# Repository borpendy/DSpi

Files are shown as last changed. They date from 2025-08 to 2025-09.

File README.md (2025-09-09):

<div align="center">
  Lower DSpi
</div>

## DSpi
The DSpi is a Dual Screen Linux handheld powered by a Rasberry Pi Compute Module 5, designed primarily for DS emulation. The device features a 5000mah amp battery, Xbox pattern controller with dual analog sticks, Dual 480p DSI touchscreens, Stereo speakers and a DAC + Headphone amp. I reccomend using the Rasbian system image provided in the above files, featuring retropie for single screen systems, and melon DS for true dual screen DS emulation (System image coming soon).

## System Specifications

- Uses any Pi CM5 module (however the CM5 lite 8GB wifi is highly recommended) with 4 A76 cores at 2.4GHz.
- 2*800x480 Waveshare IPS displays, both touchscreen.
- Stereo speakers, using 2*MAX98357 IC amplifiers, over the I2S interface.
- Headphone output, using the PCM5102 DAC + PAM8908 Headphone AMP.
- 5000 Mah LiPo battery, with 5V 3A charging using the BQ25890 1S BMS IC.
- Full size controller using RP2040, and the GP2040CE firmware, including dual analog 3ds slide pads.
- Full 3d printable chassis (In FDM!!! - Tested using neptune 4 pro, using 30% speed for hinges), using GBA SP hinges.

## Other notes
This is still a mostly experimental project, and could still use a lot of work, especially on the software side in improving the user experience. Personally if i was looking to emulate DS, I would get either a 3ds, or one of the new android emulation handhelds, however this has still been a fun project to work on. Future plans for this include swapping the main screen to the new 5" touch display 2, and making some pcb adjustments to reduce the device width.

Shield: [][cc-by-nc-sa]

This work is licensed under a
[Creative Commons Attribution-NonCommercial-ShareAlike 4.0 International License][cc-by-nc-sa].

[][cc-by-nc-sa]

[cc-by-nc-sa]: http://creativecommons.org/licenses/by-nc-sa/4.0/
[cc-by-nc-sa-image]: https://licensebuttons.net/l/by-nc-sa/4.0/88x31.png
[cc-by-nc-sa-shield]: https://img.shields.io/badge/License-CC%20BY--NC--SA%204.0-lightgrey.svg

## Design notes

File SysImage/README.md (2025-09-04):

Lite rasbian image available here: https://mega.nz/file/Jq5HgAIb#aFA1X0YDmTlBf3LAp2G1llmQ2dEHOSqhIo8WoQuP7z0
Lite image is stock rasbian + some scripts for battery functionality

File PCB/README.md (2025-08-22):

<div align="center">
  <h1>DSpi Mainboard PCB</h1>
</div>

<div align="center">
  Image of DSpi Motherboard
</div>

The DSpi PCB has a custom mainboard pcb that provides power, audio and controls to the CM5 module. This must be ordered from a PCB fabricator, and I used and recommend JLCPCB for this.
To ensure all trace impedances are correct, for the usb and display lines, you **must** order the board with the **JLC04161H-7628** layer stackup, AND **1.6 mm** thickness. Get assembly on the top side only, as most components used are SMD, and hard to hand solder. Note that the parts in jlcpcb on the bottom side are different in the final project (4.3mm rather than 6mm), so don't get bottom assembly. My recommended settings for jlcpcb are shown below:

<div align="center">
  Image of JLCPCB Settings
</div>
<p align="center">Recommended JLCPCB Settings (All other values default)</p>

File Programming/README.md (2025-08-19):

# Programming the DSpi motherboard
Some parts of the DSpi mainboard require programming after assembly. The onboard MCU (STM32) is used to control the BMS Chip settings, and must be flashed with the provided code for the mainboard to function. To do this, you need an ST-LINK, and a computer with STM32CUBEIDE - This may not be required, testing whether I2C can be set by CM5.
# Programming the DSpi controller
The DSpi controller uses the GP2040-CE architecture. To install the controller firmware, follow the setup instructions on the gp2040-ce website, seen here: https://gp2040-ce.info/installation. Use the boot button labeled on the mainboard. Once the GP2040 firmware is installed, open the web config, and change the input mode to directinput, and go to addons and enable both analog sticks, with inverted Y for both sticks. The instructions for this are here: https://gp2040-ce.info/web-configurator.
# Flashing the DSpi OS image
Use BalenaEtcher or a similar program to write the included image to an SD card, then insert into the DSpi SD slot before boot. If the correct OS is not installed and inserted, both screens will remain black after boot.

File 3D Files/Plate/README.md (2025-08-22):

Contains top cover, top plate, bottom plate, bottom cover + mount for bottom screen

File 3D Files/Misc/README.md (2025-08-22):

Contains battery mount, fan guide, fan mount, speaker grilles

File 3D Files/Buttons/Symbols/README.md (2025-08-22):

Buttons with symbols, probably need a resin printer to print

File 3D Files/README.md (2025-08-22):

## Design Files
All STLs required to build a DSpi + Blender document with all parts assembled, for reference
<div align="center">
  Image of DSpi Motherboard
  <p align="center">Full DSpi model</p>

</div>

<div align="center">
  Lower DSpi
  <p align="center">Lower half DSpi model</p>
</div>

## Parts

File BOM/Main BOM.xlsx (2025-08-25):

Major Parts: | Link: | Cost (AUD): | Note: BOM does not include assembled components
Waveshare 4.3 inch DSI Screen, touch | https://www.waveshare.com/wiki/43H-800480-IPS | $46.99
Waveshare 5 inch DSI Screen, touch | https://www.waveshare.com/50h-800480-ips.htm | $51.25
3ds slide pad * 2 | https://www.aliexpress.com/item/1005006359586643.html | $28.00
GBA SP Hinges | https://www.aliexpress.com/item/1005006352620165.html | $2.78
Micro Sd Card | Any
Pi Fan | https://www.aliexpress.com/item/1005006617984702.html | $10.00
LiPo Battery | https://www.aliexpress.com/item/1005004816868993.html
FFC Cable - 300mm | https://www.digikey.com.au/en/products/detail/raspberry-pi/SC1132/21658271 | $3.18
Speakers * 2 | https://www.digikey.com.au/en/products/detail/soberton-inc/SP-1605/3973691 | $4.94
CM5 8GB Lite | https://www.digikey.com.au/en/products/detail/raspberry-pi/SC1598/25805587 | $136.33
Speaker cables | https://www.aliexpress.com/item/1005006856354000.html | $5.00
PCB Parts:
top buttons (4.3mm) | https://www.aliexpress.com/item/4001360233985.html | $2.26
side buttons (4.5mm) | https://www.aliexpress.com/item/1005005826296317.html | $1.83
Screws as well

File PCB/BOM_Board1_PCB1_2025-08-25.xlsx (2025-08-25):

No. | Quantity | Comment | Designator | Footprint | Value | Manufacturer Part | Manufacturer | Supplier Part | Supplier
1 | 3 | TS-1088-AR02016 | BOOT,RESET,RST | SW-SMD_L3.9-W3.0-P4.45 |  | TS-1088-AR02016 | XUNPU(讯普) | C720477 | LCSC
2 | 2 | 33pF | C2,C62 | C0402 |  | 0402CG330J500NT | FH(风华) | C1562 | LCSC
3 | 14 | 10uF | C3,C5,C6,C9,C18,C19,C20,C26,C36,C40,C42,C52,C53,C66 | C0805 | 10uF | CL21A106KAYNNNE | SAMSUNG(三星) | C15850 | LCSC
4 | 13 | 100nF | C7,C13,C14,C15,C16,C55,C58,C59,C60,C61,C63,C64,C65 | C0402 |  | CL05B104KO5NNNC | SAMSUNG(三星) | C1525 | LCSC
5 | 3 | 22uF | C10,C11,C12 | C0805 | 22uF | CL21A226MAQNNNE | SAMSUNG(三星) | C45783 | LCSC
6 | 11 | 1uF | C17,C25,C33,C37,C82,C83,C84,C85,C87,C88,C89 | C0603 | 1uF | CL10A105KB8NNNC | SAMSUNG(三星) | C15849 | LCSC
7 | 10 | 100nF | C27,C28,C29,C30,C41,C43,C54,C67,C68,C69 | C0402 | 100nF | CL05B104KB54PNC | SAMSUNG(三星) | C307331 | LCSC
8 | 1 | 47nF | C34 | C0603 | 47nF | CL10B473KB8NNNC | SAMSUNG(三星) | C1622 | LCSC
9 | 1 | 4.7uF | C35 | C0603 | 4.7uF | CL10A475KO8NNNC | SAMSUNG(三星) | C19666 | LCSC
10 | 2 | 47uF | C38,C39 | C1206 | 47uF | CL31A476MPHNNNE | SAMSUNG(三星) | C96123 | LCSC
11 | 2 | 1uF | C56,C57 | C0402 |  | CL05A105KA5NQNC | SAMSUNG(三星) | C52923 | LCSC
12 | 3 | 2.2uF | C70,C71,C86 | C0603 | 2.2uF | CL10A225KO8NNNC | SAMSUNG(三星) | C23630 | LCSC
13 | 4 | 10uF | C72,C73,C74,C75 | C0805 | 10uF | GRM21BR61H106KE43L | muRata(村田) | C440198 | LCSC
14 | 4 | 100nF | C76,C77,C78,C79 | C0603 | 100nF | CC0603KRX7R9BB104 | YAGEO(国巨) | C14663 | LCSC
15 | 2 | 2.2nF | C80,C81 | C0805 | 2.2nF | CL21C222JBFNNNE | SAMSUNG(三星) | C28260 | LCSC
16 | 2 | 20pF | C92,C93 | C0402 | 20pF | 0402CG200J500NT | FH(风华) | C1554 | LCSC
17 | 1 | 100nF | C94 | C0402 | 100nF | CL05B104KO5NNNC | SAMSUNG(三星) | C1525 | LCSC
18 | 1 | 5033981892 | CARD1 | TF-SMD_503398-1892 |  | 5033981892 | MOLEX | C428492 | LCSC
19 | 2 | DF40HC(3.0)-100DS-0.4V(51) | CN1,CN2 | CONN-SMD_DF40HC-3.0-100DS-0.4V-51 |  | DF40HC(3.0)-100DS-0.4V(51) | HRS(广濑) | C424649 | LCSC
20 | 1 | B2B-PH-K-S(LF)(SN) | CN5 | CONN-TH_B2B-PH-K-S |  | B2B-PH-K-S(LF)(SN) | JST | C131337 | LCSC
21 | 1 | BM04B-SRSS-TB(LF)(SN) | CN10 | CONN-SMD_BM04B-SRSS-TB |  | BM04B-SRSS-TB(LF)(SN) | JST | C160390 | LCSC
22 | 1 | PJ-320D | CN12 | AUDIO-SMD_PJ-320D |  | PJ-320D | SHOU HAN(首韩) | C431535 | LCSC
23 | 2 | AFC01-S22FCA-00 | FPC1,FPC2 | FPC-SMD_P0.5-22P_FGS-XJ-H2.0 |  | AFC01-S22FCA-00 | JS(钜硕电子) | C262668 | LCSC
24 | 1 | PZ254V-11-05P | H3 | hdr-th_5p-p2.54-v-m |  | PZ254V-11-05P | XFCN(兴飞) | C492404 | LCSC
25 | 2 | 1uH | L2,L3 | IND-SMD_L4.4-W4.2 | 1uH | FXL0420-1R0-M | cjiang(长江微电) | C167203 | LCSC
26 | 2 | KT-0603W | LED1,LED2 | LED0603-R-RD_WHITE |  | KT-0603W | KENTO | C2290 | LCSC
27 | 2 | KT-0603R | LED3,LED4 | LED0603-RD |  | KT-0603R | KENTO | C2286 | LCSC
28 | 4 | 2.2kΩ | R1,R3,R4,R5 | R0402 | 2.2kΩ | 0402WGF2201TCE | UNI-ROYAL(厚声) | C25879 | LCSC
29 | 1 | 15kΩ | R2 | R0402 | 15kΩ | 0402WGF1502TCE | UNI-ROYAL(厚声) | C25756 | LCSC
30 | 3 | 1kΩ | R6,R39,R55 | R0402 | 1kΩ | 0402WGF1001TCE | UNI-ROYAL(厚声) | C11702 | LCSC
31 | 2 | 5.1kΩ | R11,R12 | R0402 | 5.1kΩ | 0402WGF5101TCE | UNI-ROYAL(厚声) | C25905 | LCSC
32 | 1 | 120Ω | R16 | R0603 | 120Ω | 0603WAF1200T5E | UNI-ROYAL(厚声) | C22787 | LCSC
33 | 3 | 10kΩ | R17,R18,R31 | R0603 | 10kΩ | 0603WAF1002T5E | UNI-ROYAL(厚声) | C25804 | LCSC
34 | 1 | 4.7kΩ | R27 | R0402 | 4.7kΩ | 0402WGF4701TCE | UNI-ROYAL(厚声) | C25900 | LCSC
35 | 1 | 750kΩ | R29 | R0603 | 750kΩ | 0603WAF7503T5E | UNI-ROYAL(厚声) | C23240 | LCSC
36 | 1 | 100kΩ | R30 | R0603 | 100kΩ | 0603WAF1003T5E | UNI-ROYAL(厚声) | C25803 | LCSC
37 | 1 | 1.5kΩ | R32 | R0402 | 1.5kΩ | 0402WGF1501TCE | UNI-ROYAL(厚声) | C25867 | LCSC
38 | 1 | 220kΩ | R34 | R0402 | 220kΩ | 0402WGF2203TCE | UNI-ROYAL(厚声) | C25767 | LCSC
39 | 2 | 10kΩ | R37,R38 | R0402 | 10kΩ | 0402WGF1002TCE | UNI-ROYAL(厚声) | C25744 | LCSC
40 | 4 | 56kΩ | R43,R44,R45,R46 | R0402 | 56kΩ | 0402WGF5602TCE | UNI-ROYAL(厚声) | C25796 | LCSC
41 | 2 | 22Ω | R47,R48 | R0402 |  | 0402WGF220JTCE | UNI-ROYAL(厚声) | C25092 | LCSC
42 | 4 | 1kΩ | R49,R50,R51,R54 | R0402 |  | 0402WGF1001TCE | UNI-ROYAL(厚声) | C11702 | LCSC
43 | 2 | 10kΩ | R52,R53 | R0402 |  | 0402WGF1002TCE | UNI-ROYAL(厚声) | C25744 | LCSC
44 | 2 | 470Ω | R56,R57 | R0805 | 470Ω | 0805W8F4700T5E | UNI-ROYAL(厚声) | C17710 | LCSC
45 | 2 | BM02B-SURS-TF(LF)(SN) | SPKR_L,SPKR_R | CONN-SMD_2P-P0.80_BM02B-SURS-TF-LF-SN |  | BM02B-SURS-TF(LF)(SN) | JST | C385130 | LCSC
46 | 2 | FH19C-4S-0.5SH(10) | STICK-L,STICK-R | FPC-SMD_FH19C-4S-0.5SH |  | FH19C-4S-0.5SH(10) | HRS(广濑) | C424650 | LCSC
47 | 1 | AP22653W6-7 | U1 | SOT-23-6_L2.9-W1.6-P0.95-LS2.8-BR |  | AP22653W6-7 | DIODES(美台) | C2158037 | LCSC
48 | 1 | HDMI-519S | U2 | HDMI-SMD_19P-P0.40-H-F_HDMI-519S |  | HDMI-519S | SOFNG(硕方) | C183605 | LCSC
49 | 3 | RT9742GGJ5 | U4,U15,U19 | TSOT-23-5_L2.9-W1.6-P0.95-LS2.8-BR |  | RT9742GGJ5 | RICHTEK(立锜) | C250547 | LCSC
50 | 1 | STM32F103C8T6 | U5 | LQFP-48_L7.0-W7.0-P0.50-LS9.0-BL |  | STM32F103C8T6 | ST(意法半导体) | C8734 | LCSC
51 | 1 | BQ25890RTWR | U8 | WQFN-24_L4.0-W4.0-P0.50-BL-EP |  | BQ25890RTWR | TI(德州仪器) | C130451 | LCSC
52 | 1 | TPS61022RWUR | U9 | VQFN-7_L2.0-W2.0-P0.55-TL_RWU |  | TPS61022RWUR | TI(德州仪器) | C915088 | LCSC
53 | 2 | MAX98357AETE+T | U11,U12 | TQFN-16_L3.0-W3.0-P0.50-BL-EP1.5 |  | MAX98357AETE+T | ADI(亚德诺)/MAXIM(美信) | C910544 | LCSC
54 | 1 | RP2040 | U16 | LQFN-56_L7.0-W7.0-P0.4-EP |  | RP2040 | Raspberry Pi(树莓派) | C2040 | LCSC
55 | 1 | W25Q128JVSIQTR | U17 | SOIC-8_L5.3-W5.3-P1.27-LS8.0-BL |  | W25Q128JVSIQ | WINBOND(华邦) | C97521 | LCSC
56 | 1 | TPSPX3819M5-L-3-3 | U18 | SOT-23-5_L3.0-W1.6-P0.95-LS2.8-BR |  | TPSPX3819M5-L-3-3 | TECH PUBLIC(台舟) | C5370980 | LCSC
57 | 1 | PCM5102APWR | U20 | TSSOP-20_L6.5-W4.4-P0.65-LS6.4-BL |  | PCM5102APWR | TI(德州仪器) | C107671 | LCSC
58 | 1 | PAM8908JER | U21 | QFN-16_L3.0-W3.0-P0.50-BL-EP1.7 |  | PAM8908JER | DIODES(美台) | C33233 | LCSC
59 | 1 | TYPE-C-31-M-17 | USB2 | USB-C-SMD_10P-P1.00-L6.8-W8.9 |  | TYPE-C-31-M-17 | 韩国韩荣 | C283540 | LCSC
60 | 2 | TYPE-C-31-M-12 | USBC1,USBC2 | USB-C_SMD-TYPE-C-31-M-12 |  | TYPE-C-31-M-12 | 韩国韩荣 | C165948 | LCSC
61 | 1 | 12MHz | X1 | OSC-SMD_4P-L3.2-W2.5-BL |  | X322512MSB4SI | YXC | C9002 | LCSC
62 | 1 | 8MHz | X2 | CRYSTAL-SMD_L5.0-W3.2 | 8MHz | X50328MSB2GI | YXC(扬兴晶振) | C115962 | LCSC

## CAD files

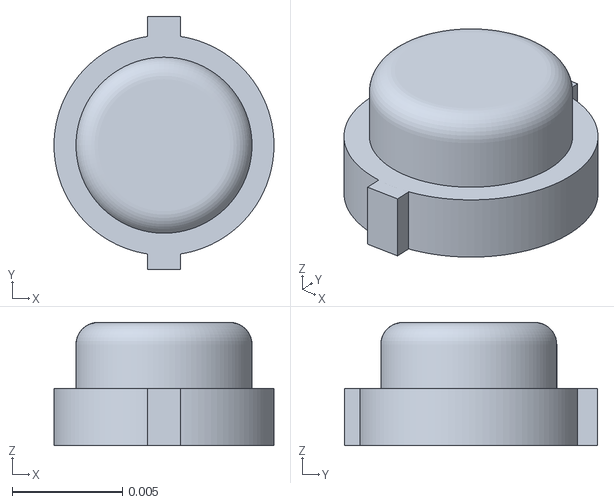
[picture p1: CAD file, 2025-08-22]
3D Files/Buttons/Nosymbols/topbutton.stl
0.01 x 0.0115 x 0.0056

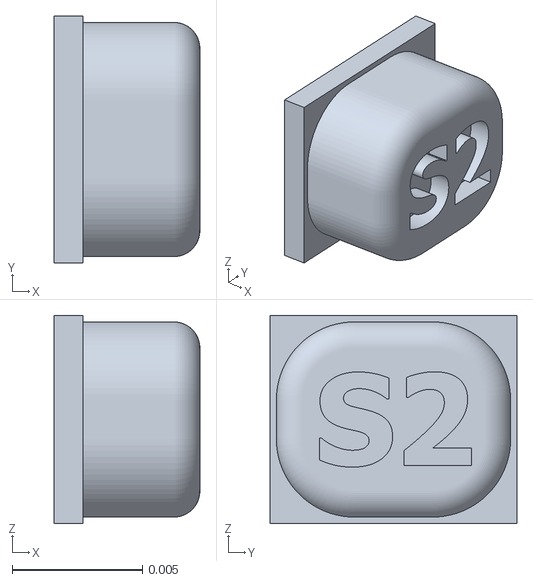
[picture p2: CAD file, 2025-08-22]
3D Files/Buttons/Symbols/s2.stl
0.0056 x 0.00949 x 0.008

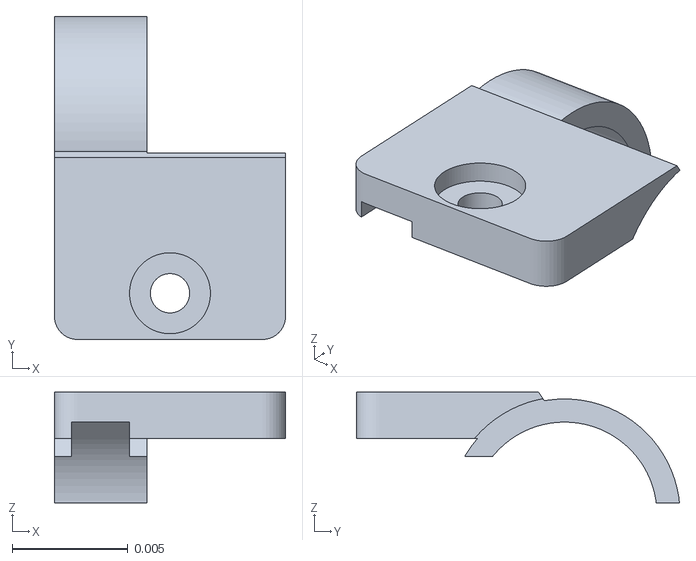
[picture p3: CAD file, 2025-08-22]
3D Files/Hinge/topcover-r.stl
0.01 x 0.014 x 0.0048

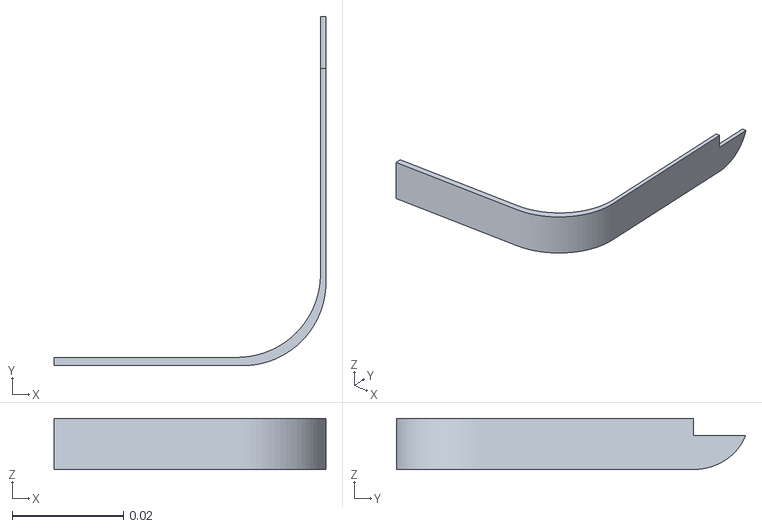
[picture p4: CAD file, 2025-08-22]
3D Files/Misc/fanguide2.stl
0.049 x 0.0629 x 0.0092

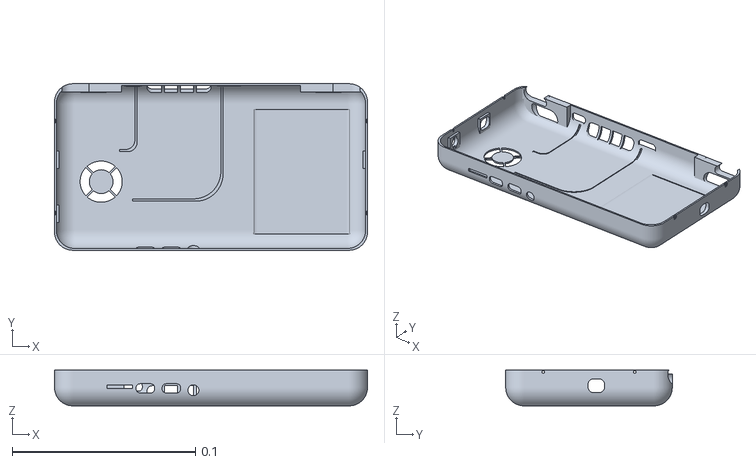
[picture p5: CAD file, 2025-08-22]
3D Files/Plate/bottomcover.stl
0.171 x 0.091 x 0.0195

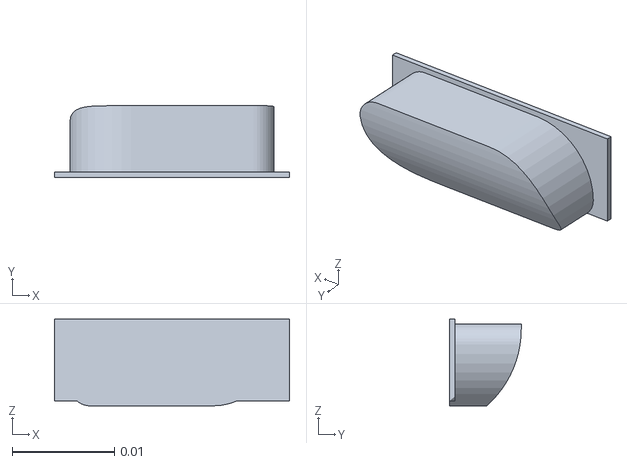
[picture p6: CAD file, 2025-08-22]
3D Files/Buttons/Nosymbols/trigger.stl
0.023 x 0.007 x 0.0085

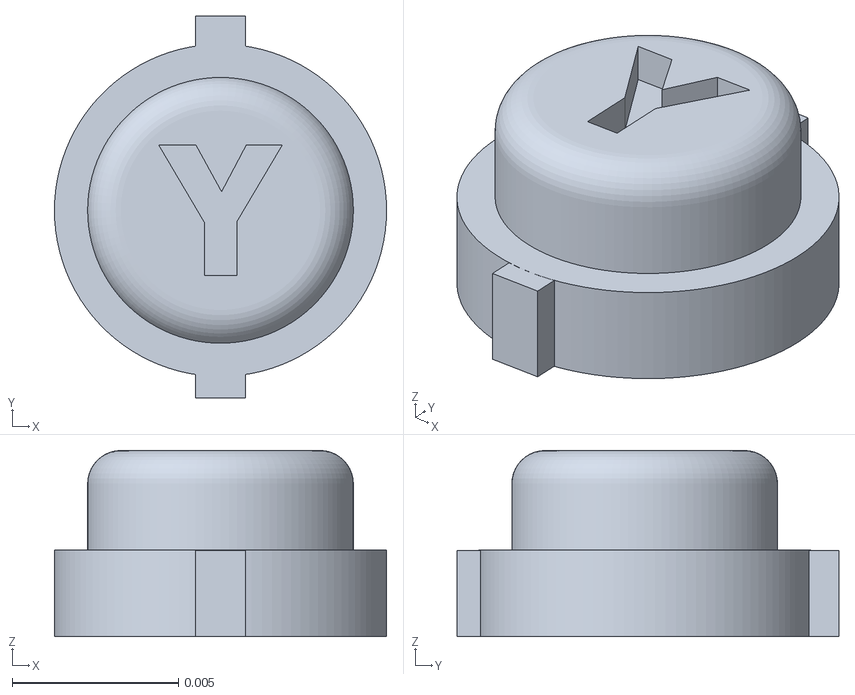
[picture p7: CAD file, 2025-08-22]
3D Files/Buttons/Symbols/y.stl
0.01 x 0.0115 x 0.0056

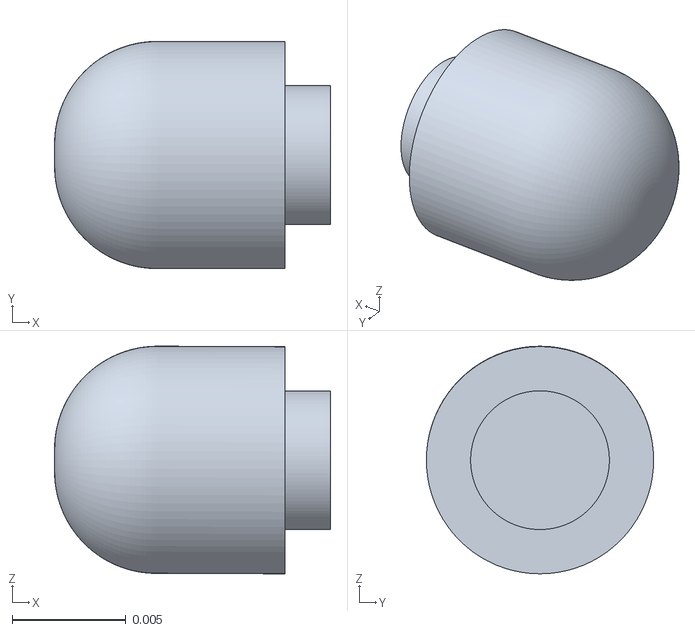
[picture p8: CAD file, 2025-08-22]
3D Files/Hinge/endcap.stl
0.0121 x 0.00999 x 0.01

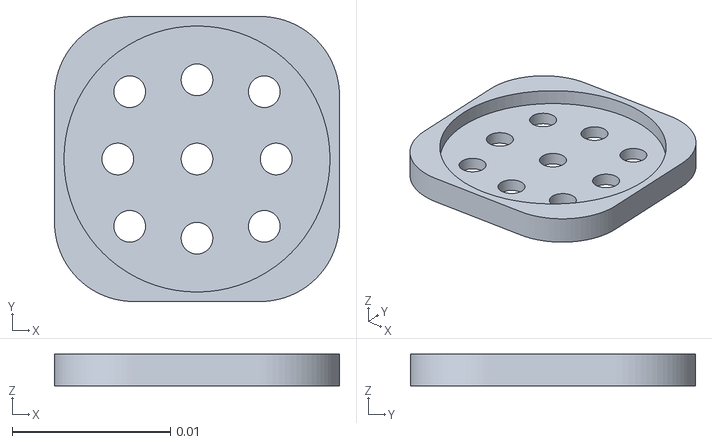
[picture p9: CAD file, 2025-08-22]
3D Files/Misc/speakergrille.stl
0.018 x 0.018 x 0.002

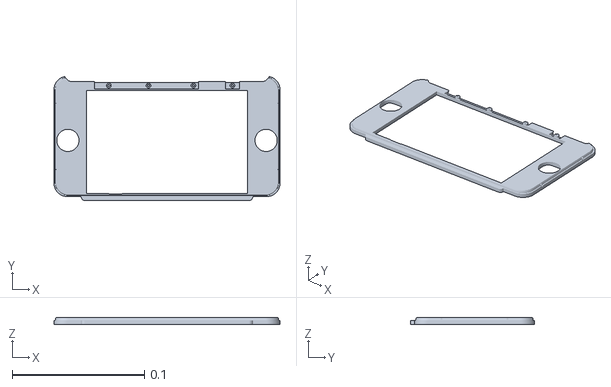
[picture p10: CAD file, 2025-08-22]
3D Files/Plate/topframe.stl
0.171 x 0.0938 x 0.005

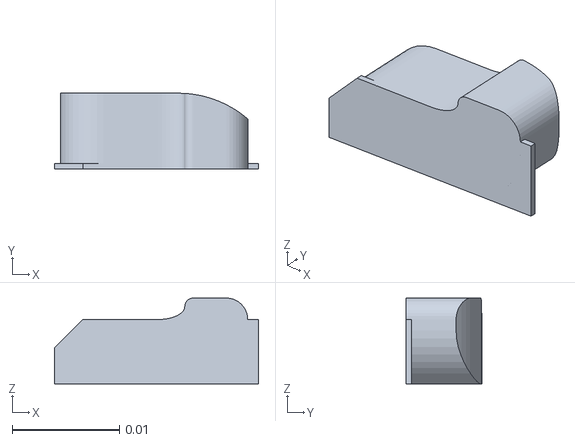
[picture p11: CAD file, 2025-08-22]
3D Files/Buttons/Nosymbols/bumper.stl
0.019 x 0.00705 x 0.008

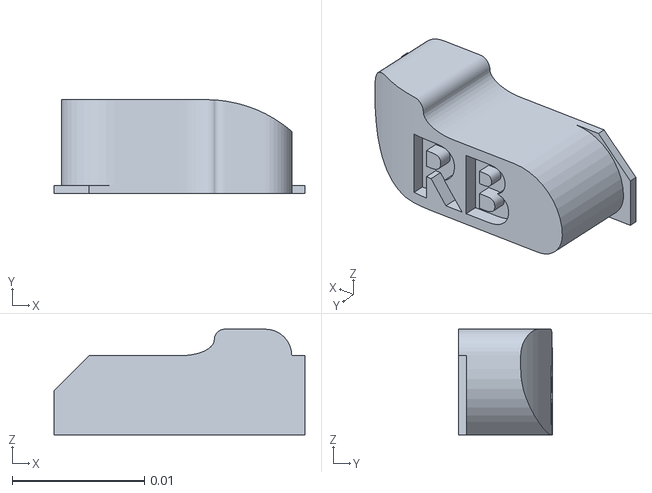
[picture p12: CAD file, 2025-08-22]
3D Files/Buttons/Symbols/rb.stl
0.019 x 0.0071 x 0.008

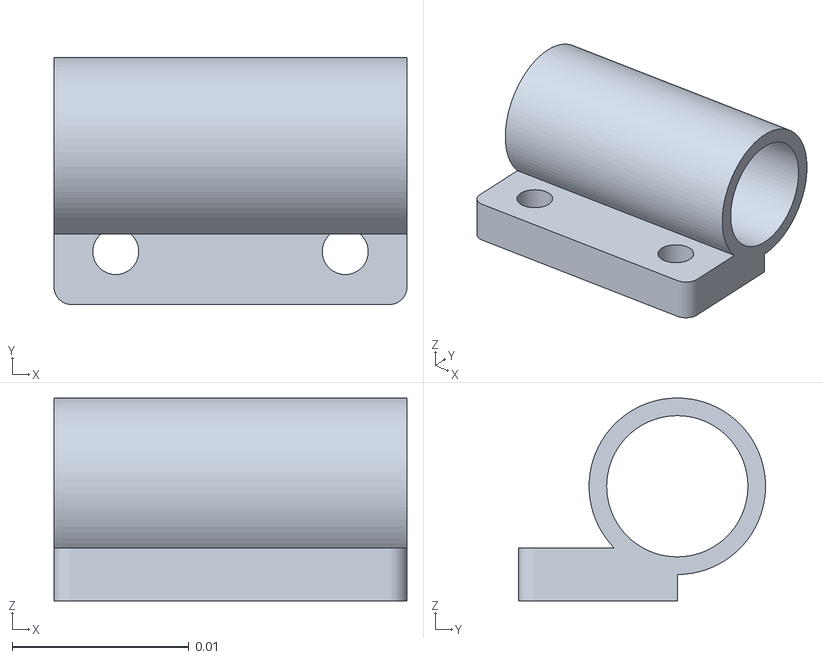
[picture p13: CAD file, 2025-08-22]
3D Files/Hinge/hinge-bottommiddle.stl
0.02 x 0.014 x 0.0115

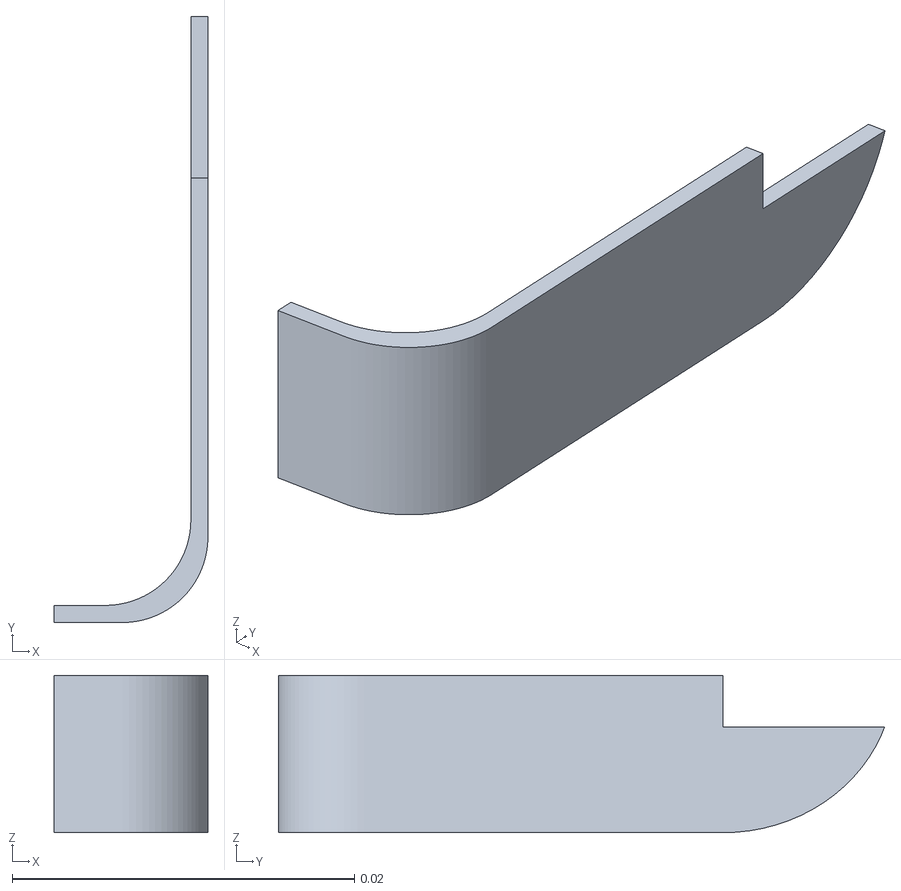
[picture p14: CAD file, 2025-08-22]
3D Files/Misc/fanguide1.stl
0.009 x 0.0354 x 0.0092

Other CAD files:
3D Files/Plate/topcover.stl
3D Files/Buttons/Nosymbols/powerbutton.stl
3D Files/Buttons/Symbols/rt.stl
3D Files/Hinge/hinge-bottomleft.stl
3D Files/Buttons/Nosymbols/sidebutton.stl
3D Files/Buttons/Symbols/a.stl
3D Files/Buttons/Symbols/b.stl
3D Files/Buttons/Symbols/dpad.stl
3D Files/Buttons/Symbols/lb.stl
3D Files/Buttons/Symbols/ls.stl
3D Files/Buttons/Symbols/lt.stl
3D Files/Buttons/Symbols/menu.stl
3D Files/Buttons/Symbols/power.stl
3D Files/Buttons/Symbols/rs.stl
3D Files/Buttons/Symbols/s1.stl
3D Files/Buttons/Symbols/select.stl
3D Files/Buttons/Symbols/start.stl
3D Files/Buttons/Symbols/x.stl
3D Files/Hinge/hinge-bottomright.stl
3D Files/Hinge/hinge-topleft.stl
3D Files/Hinge/hinge-topright.stl
3D Files/Hinge/topcover-l.stl
3D Files/Misc/batterymount.stl
3D Files/Misc/fanmount.stl
3D Files/Plate/bottomplate.stl
3D Files/Plate/lowerscreenmount-back.stl
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

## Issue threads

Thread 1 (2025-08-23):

Missing Information Concerning Screen Size

timbo2040, 2025-08-23:
You have given key information concerning the resolution of the displays used, but not on the physical size of the displays. After a Google search, I have found two diffing models with the same 800x400 resolution you mentioned, but they are different physical sizes. If you could please update the readme to make this clear, it would be greatly appreciated.

borpendy, 2025-08-25:
I'll post a BOM later this week containing all the components.

borpendy, 2025-08-25:
BOM added with links to screen models used

Closed 2025-08-25.

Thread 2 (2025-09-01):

how many days?

si-open, 2025-09-01:
How many days of continuous non-stop play can this device withstand on a single charge?

borpendy, 2025-09-04:
Around 3hrs from testing. the cm5 is pretty power intensive.

Closed 2025-09-04.

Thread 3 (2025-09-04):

I2C malfunctioning

borpendy, 2025-09-04:
Due to direct connection between i2c and cm5, when the cm5 is off, the i2c bus is held low, preventing operation. Can be fixed by placing POWER_OFF_ON_HALT = 0 in eeprom settings, but this comes with unacceptable power penalty (1.5W idle usage). Will fix properly with next device revision.

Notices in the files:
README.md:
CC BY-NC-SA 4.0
